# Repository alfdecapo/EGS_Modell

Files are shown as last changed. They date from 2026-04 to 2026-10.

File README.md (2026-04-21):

# EGS Modell
Dateispeicher und Entwicklungsdaten für das Einsatz-Gerüst-System als Modellbausatz.
Das Modell hat einen Maßstab 1:7,7.

Beispiel:
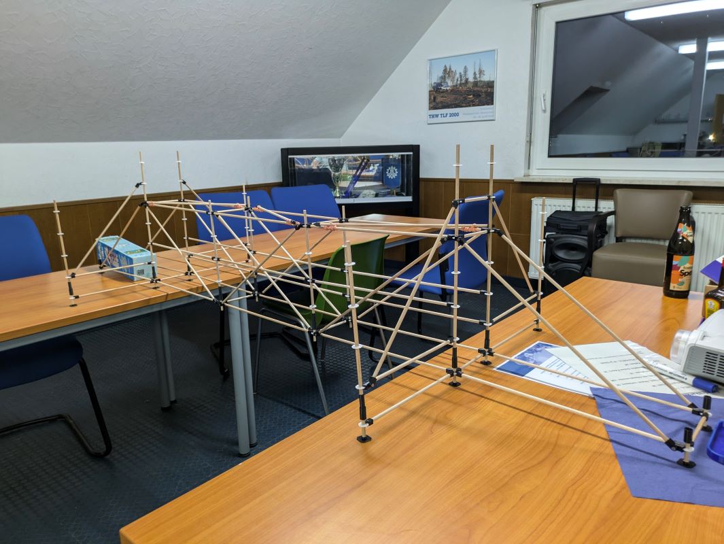
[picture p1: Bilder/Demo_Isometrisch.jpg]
Bild vom freitrageneden Steg


## 🛠️ Vorbereitung

Bevor du mit dem Druck startest, beachte bitte diesen Ablauf, um unnötige Druckstunden und Fehlkäufe bei den Zukaufteilen zu vermeiden.
### 1. Toleranz-Check (Schnappverbindungen)
Das Projekt setzt auf Schnappverbindungen. Da 3D-Drucker das Modell oft mit minimalen Abweichungen umsetzen, ist die Passgenauigkeit entscheidend:
* Testdruck: Drucke zuerst nur die Verbindungsstellen:
	* Flansch
	* Diagonale Keilschloss
	* Horizontale Keilschloss
* Anpassung: Sollten die Teile nicht sauber einrasten, [nimm die Korrekturen gezielt in der FreeCAD-Datei vor](#-software--mitwirken).

### 2. Umfang & Beschaffung
Da es sich um einen modularen Bausatz handelt, variiert der Bedarf je nach gewählter Gerüst-Größe.
 [Siehe dazu die Materialplanung.](Anleitungen/Materialplanung.md) 
 Es empfielt sich erst mit der Bodengruppe zu beginnen, da diese in fast jedem anderen Bausatz wiederfindet.

## 🏗️ Montageanleitungen
* [Materialplanung](Anleitungen/Materialplanung.md)
* [Zusammenbau Boden](Anleitungen/ZusammenbauBoden.md)
* [Zusammenbau Diagonale](Anleitungen/ZusammenbauDiagonale.md)
* [Zusammenbau Drehkupplung](Anleitungen/ZusammenbauDrehkupplung.md)
* [Zusammenbau Fuß](Anleitungen/ZusammenbauFuss.md)
* [Zusammenbau Riegel](Anleitungen/ZusammenbauRiegel.md)
* [Zusammenbau Vertikale](Anleitungen/ZusammenbauVertikale.md)

## ❓ Fragen & Problemlösungen
Sollten in den Montageanleitungen noch Fragen offen bleiben kann die FAQ Seite weiter helfen.

👉 **[Hier geht es zur separaten FAQ-Seite](FAQ.md)**

## 🛠 Software & Mitwirken

Das Projekt wird zukünftig primär mit **FreeCAD** entwickelt. Wenn du Änderungen vornehmen möchtest, nutze bitte die Dateien im Ordner `CAD Dateien/FreeCAD/`.

* **Download:** [FreeCAD herunterladen (Open Source)](https://www.freecad.org/)

### Workflow für Mitwirkende:
1. Quelldatei in **FreeCAD** bearbeiten.
2. Nach Änderungen die betroffenen Bauteile als **.stl** exportieren.
3. Die neuen **.stl** Dateien im Ordner **`Drucker Dateien/`** speichern.

## ⚙️ Export-Einstellungen
Damit die Druckdateien konsistent bleiben:
* **Format:** STL
* **Einheit:** mm
* **Speicherort:** `/Drucker Dateien/`

## 📄 Lizenz

Dieses Projekt ist unter der **GNU General Public License v3.0 (GPLv3)** lizenziert.

**Was das bedeutet:**
* ✅ **Freie Nutzung:** Du darfst die CAD-Dateien privat und kommerziell nutzen.
* ✅ **Änderungen:** Du darfst die Modelle verändern und verbessern.
* ⚠️ **Weitergabe:** Wenn du das Projekt oder eine veränderte Version davon verbreitest, **muss** dies ebenfalls unter der GPLv3 geschehen und der Quellcode (die originalen CAD-Dateien, nicht nur STLs!) muss offen zugänglich sein.

Details findest du in der [LICENSE](LICENSE) Datei.

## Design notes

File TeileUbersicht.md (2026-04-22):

# Übersicht über die Druck-Teile

|  | Dateiname | Bezeichnung der Anleitung | Anleitungen |
| - | - | - | - |
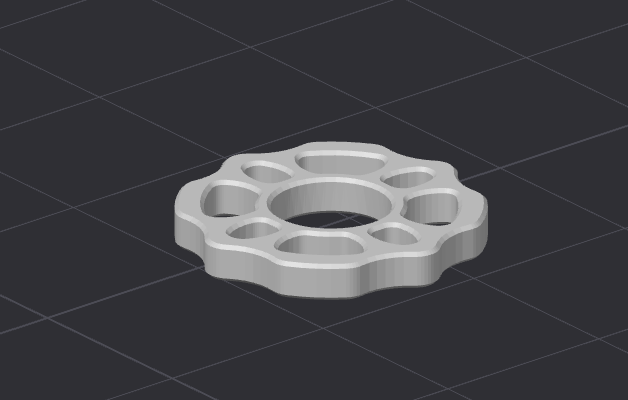
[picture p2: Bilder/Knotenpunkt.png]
Bild
|  | [Flansch 1zu7.7](Drucker-Dateien/Flansch-1zu7.7.STL) | Flansch | [Vertikalstangen](Anleitungen/ZusammenbauVertikale.md)<br>[Füße und Anfangstücke](Anleitungen/ZusammenbauFuss.md) |
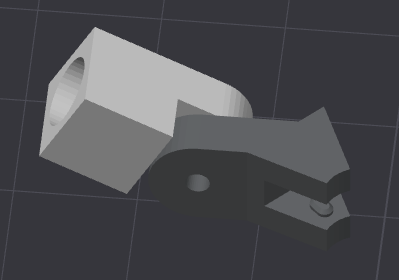
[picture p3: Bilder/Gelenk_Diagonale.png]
Bild
|  | [Diagonale Gelenk](Drucker-Dateien/Diagonale-Gelenk.STL) | Gelenk | [Diagonalstangen](Anleitungen/ZusammenbauDiagonale.md) |
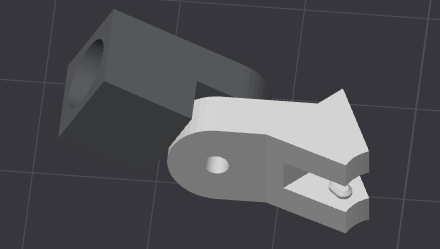
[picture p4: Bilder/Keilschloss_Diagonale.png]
Bild
|  | [Diagonale Keilschloss](Drucker-Dateien/Diagonale-Keilschloss.STL) | Keilschloss | [Diagonalstangen](Anleitungen/ZusammenbauDiagonale.md) |
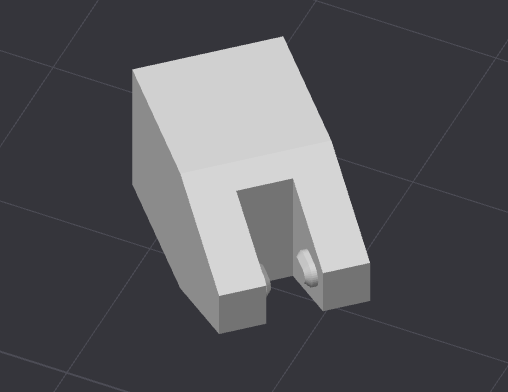
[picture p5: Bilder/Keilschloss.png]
Bild
|  | [Horizontale Keilschloss](Drucker-Dateien/Horizontale-Keilschloss.STL) | Keilschloss | [Riegel](Anleitungen/ZusammenbauRiegel.md) |
| [![Bild]()](Drucker-Dateien/Vertikalen-Verbinder.STL) | [Vertikalen Verbinder](Drucker-Dateien/Vertikalen-Verbinder.STL) | Adapter | [Vertikalstangen](Anleitungen/ZusammenbauVertikale.md) |
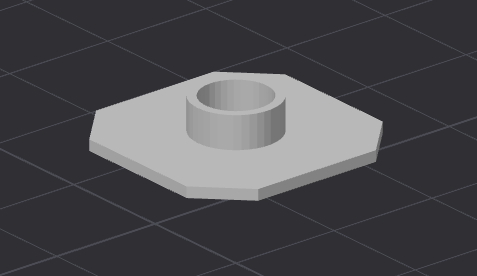
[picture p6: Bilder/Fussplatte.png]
Bild
|  | [Fuß](Drucker-Dateien/Fuß.STL) | Fuß | [Füße und Anfangstücke](Anleitungen/ZusammenbauFuss.md) |
| [![Bild]()](Drucker-Dateien/Fußadapter-Simpel.STL) | [Fußadapter Simpel](Drucker-Dateien/Fußadapter-Simpel.STL) | Adapter | [Füße und Anfangstücke](Anleitungen/ZusammenbauFuss.md) |
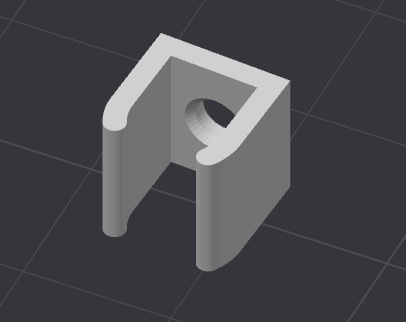
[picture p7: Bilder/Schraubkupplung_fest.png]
Bild
|  | [Drehkupplung Klemme](Drucker-Dateien/Drehkupplung-Klemme.STL) | Klemme | [Drehkupplung](Anleitungen/ZusammenbauDrehkupplung.md) |
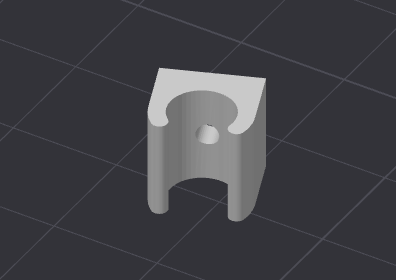
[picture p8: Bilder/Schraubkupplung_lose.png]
Bild
|  | [Drehkupplung Lose](Drucker-Dateien/Drehkupplung-Lose.STL) | Lose | [Drehkupplung](Anleitungen/ZusammenbauDrehkupplung.md) |
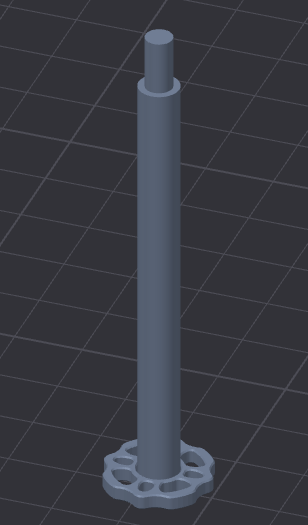
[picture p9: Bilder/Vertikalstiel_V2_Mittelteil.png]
Bild
| | [Vertikalstiel V2 Mittelteil](Drucker-Dateien/Vertikalstiel_V2_Mittelteil.STL)|Stiel_V2_Mittelteil|[Stiel_V2_Mittelteil](Anleitungen/Zusammenbau_Vertikalstiel_V2.md)|

## Sonstige Dateien

|  | Dateiname | Kommentar |
| - | - | - |
| [![Bild]()] | [Boden 3m breit](Drucker-Dateien/Boden-3m-breit.STL) | Der breite 3m Boden in einem Stück. Passt nicht in die meisten Drucker hinein |
| [![Bild]()] | [Boden 3m schmal](Drucker-Dateien/Boden-3m-schmal.STL) | Der schmale 3m Boden in einem Stück. Passt nicht in die meisten Drucker hinein |
| [![Bild]()] | [Flansch](Drucker-Dateien/Flansch.STL) | Der Flansch in orginal Größe |

---
[Zurück zur Hauptanleitung](README.md)

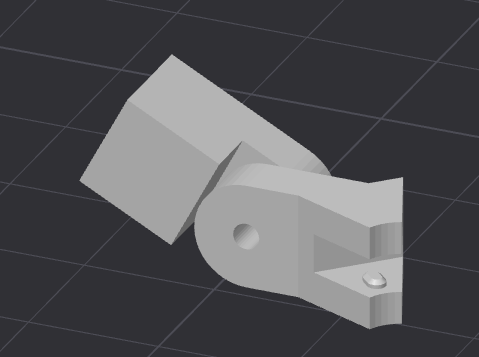
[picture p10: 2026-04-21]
Bilder/Klemmschloss_Diagonale.png

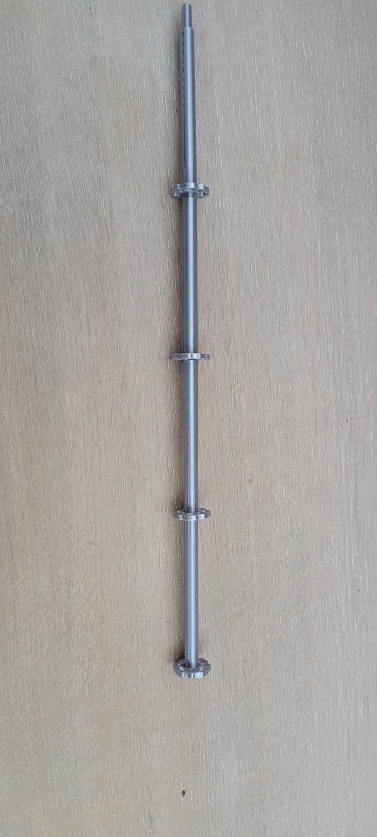
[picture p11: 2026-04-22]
Bilder/Vertikalstiel_V2_Prototyp.jpg

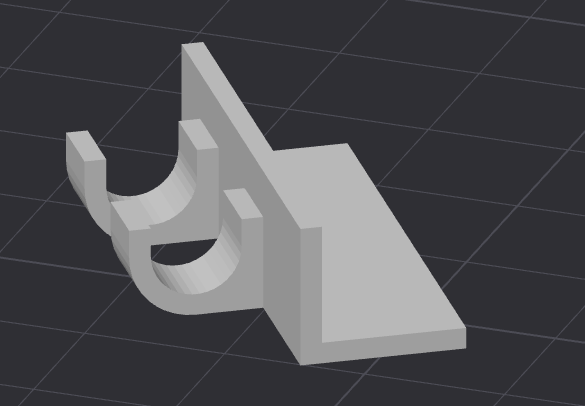
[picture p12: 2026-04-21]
Bilder/Bodenadapter schmal.png

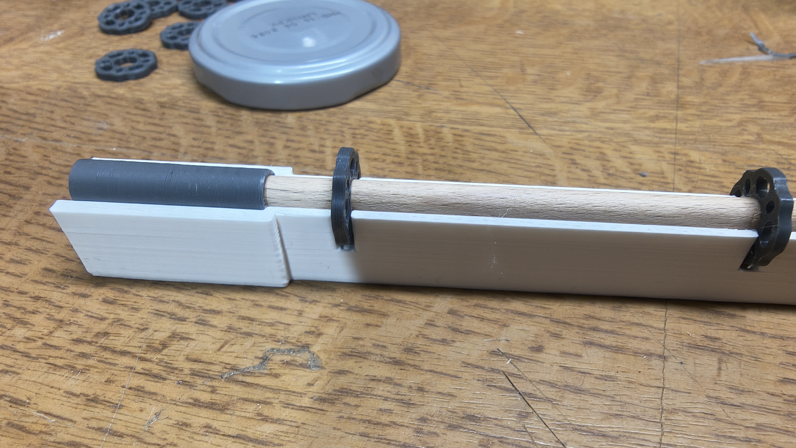
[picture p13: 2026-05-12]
Bilder/Vertikalschablone/Vertikalschablone_Kopf.jpg

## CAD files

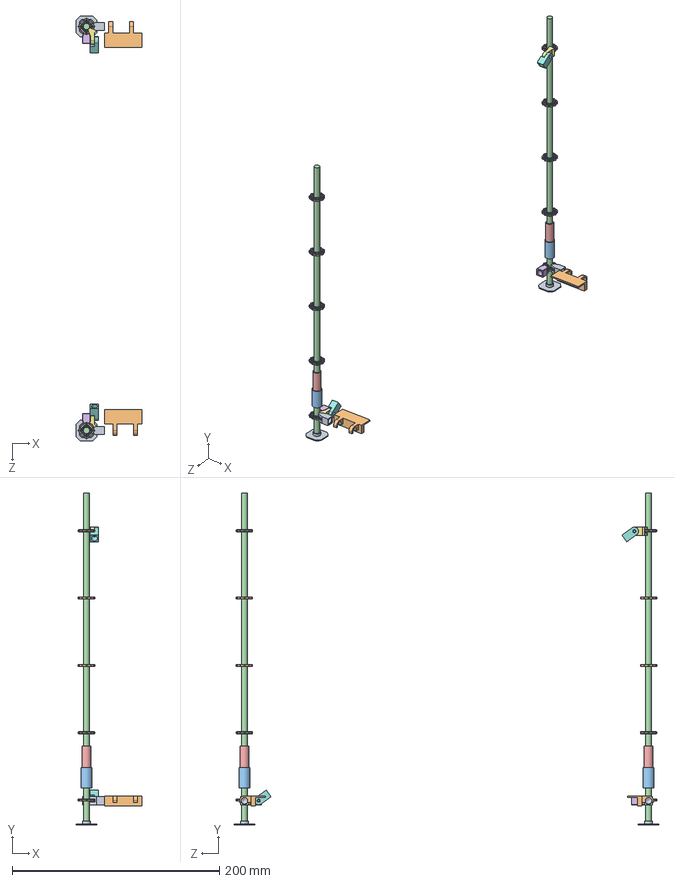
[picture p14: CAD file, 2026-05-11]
CAD Dateien/Teildruck 7.7/Ursprungsdateien Solid Works/Gesammtbau.SLDASM
63.5 x 320.4 x 410.0 mm
Fuß x 2
Rosette 1zu7.7 x 10
Fußadapter Simpel v2 x 2
Holzstangen x 4
Vertikalen Verbinder x 2
Rosettenadapter-Gerade v4 x 2
Rosettenadapter-Diagonale Verbinder v2 x 2
Rosettenadapter-Diagonale Stange x 2
Rosettenadapter-Gerade v5 x 2
Bodenadapter breit v2 x 2

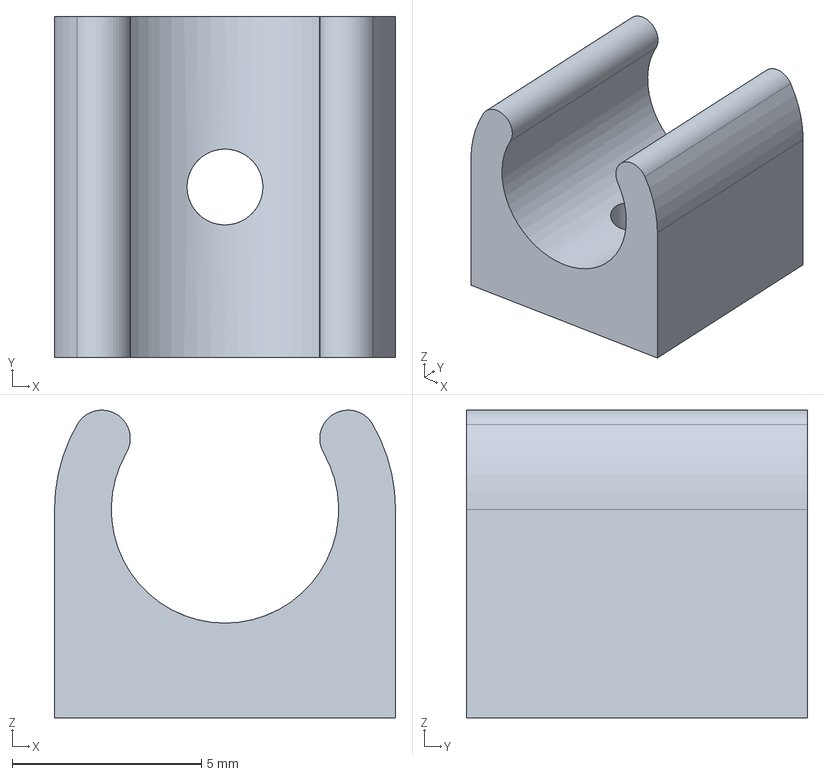
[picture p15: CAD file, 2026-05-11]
CAD Dateien/Teildruck 7.7/Drehkupplung Klemme.FCStd
9.00 x 9.00 x 8.12 mm

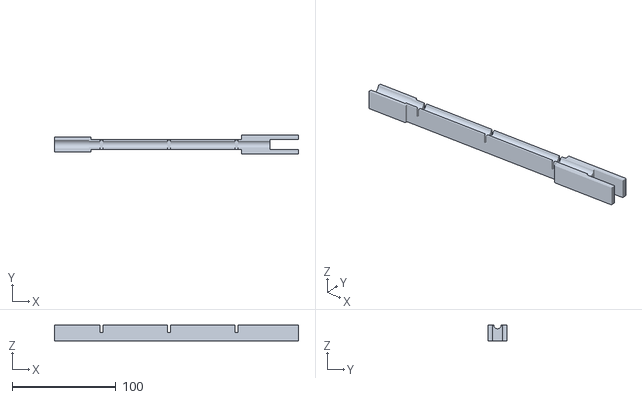
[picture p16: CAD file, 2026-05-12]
Drucker Dateien/Teildruck 7.7/Schablone EGS Vertikalstiel - Anfangsteil.stl
235.0 x 18.0 x 15.0

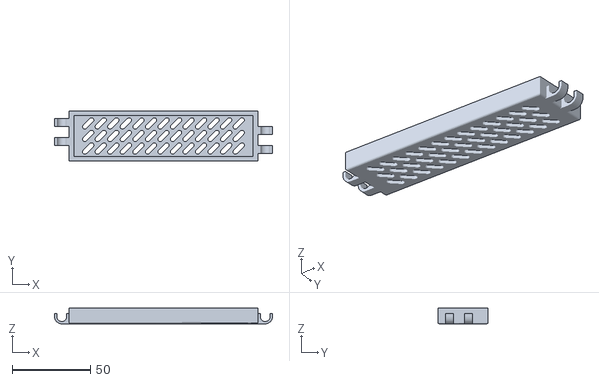
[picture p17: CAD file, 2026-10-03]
Drucker Dateien/Volldruck 7.7/Boden - 1m - Schmal.stl
138.9 x 32.0 x 10.0

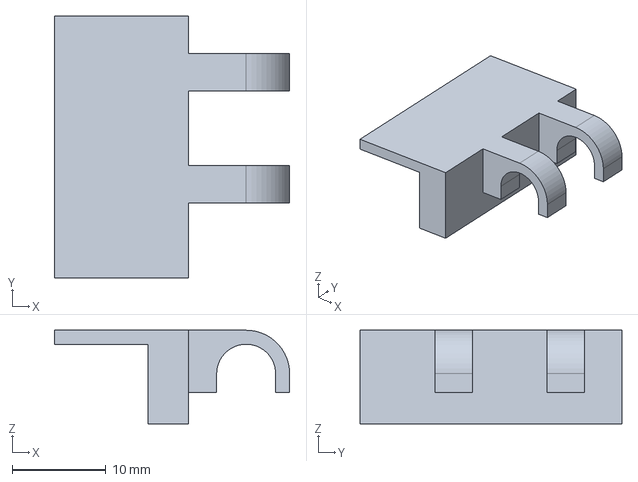
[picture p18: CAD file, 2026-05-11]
CAD Dateien/Teildruck 7.7/Bodenadapter schmal.FCStd
25.1 x 28.0 x 10.0 mm

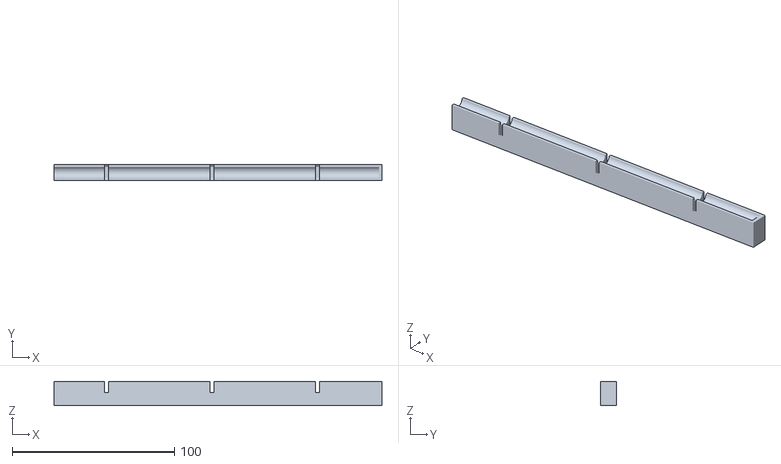
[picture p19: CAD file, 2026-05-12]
Drucker Dateien/Teildruck 7.7/Schablone EGS Vertikalstiel - Endteil.stl
202.2 x 10.0 x 15.0

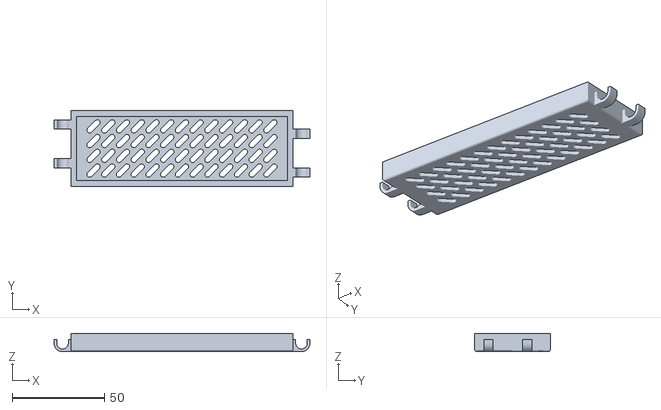
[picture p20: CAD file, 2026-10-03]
Drucker Dateien/Volldruck 7.7/Boden - 1m - Breit.stl
139.0 x 41.0 x 10.0

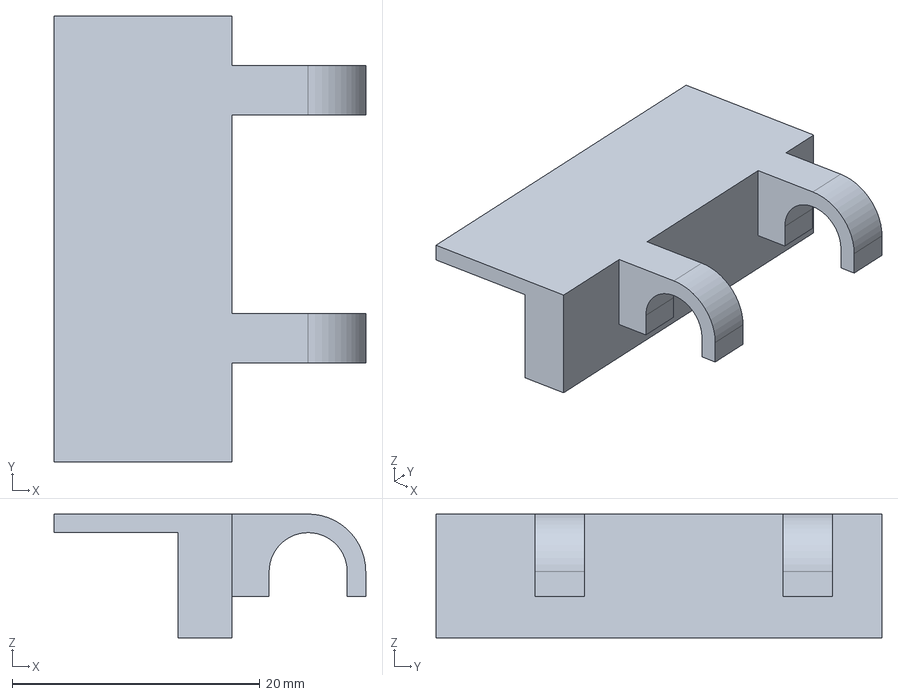
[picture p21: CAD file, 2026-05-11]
CAD Dateien/Teildruck 7.7/Bodenadapter breit.FCStd
25.1 x 36.0 x 10.0 mm

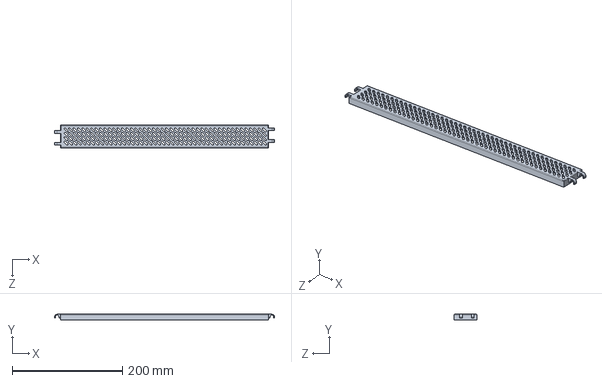
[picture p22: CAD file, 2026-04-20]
CAD Dateien/Teildruck 7.7/Ursprungsdateien Solid Works/Boden 3m breit.SLDPRT
399.3 x 10.0 x 41.0 mm

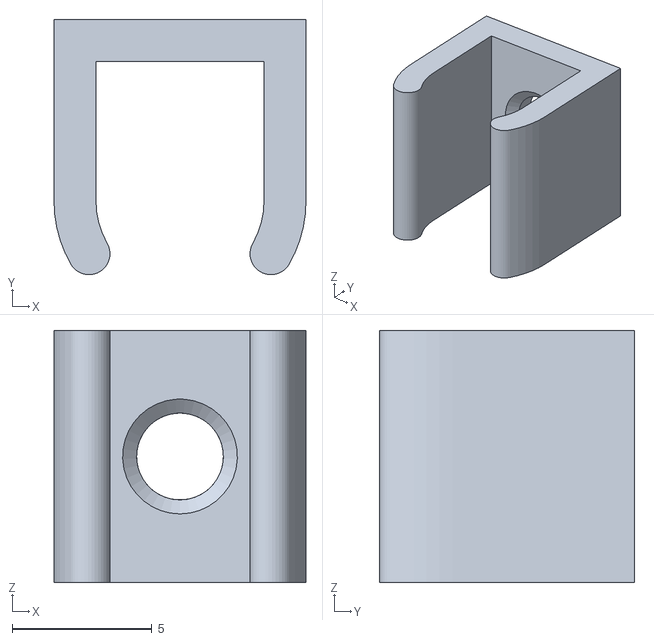
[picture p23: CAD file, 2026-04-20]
Drucker Dateien/Teildruck 7.7/Drehkupplung Lose.STL
9.00 x 9.12 x 9.00

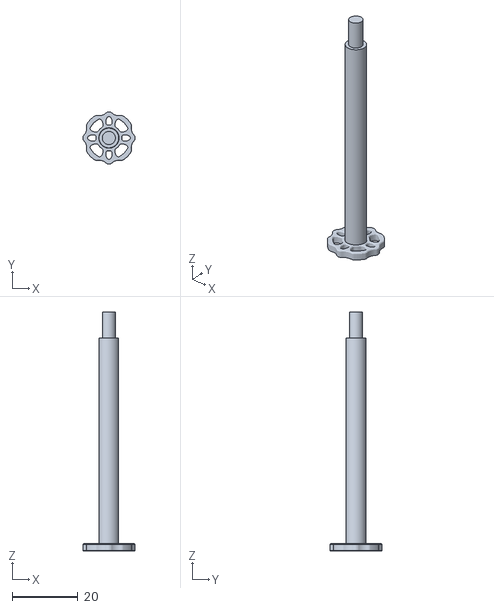
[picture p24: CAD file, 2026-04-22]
Drucker Dateien/Volldruck 7.7/Vertikalstiel_V2_Mittelteil.stl
16.0 x 16.0 x 72.9

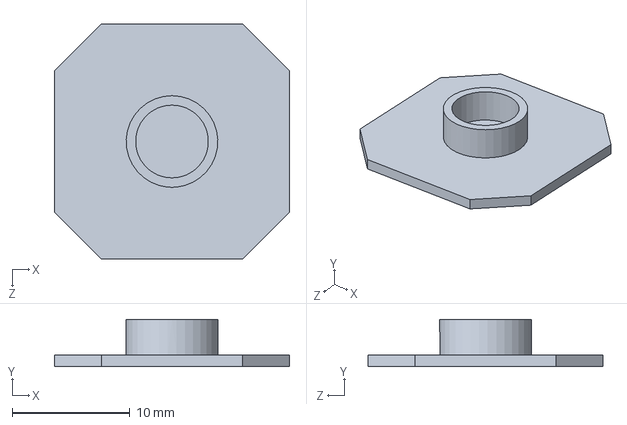
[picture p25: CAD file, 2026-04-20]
CAD Dateien/Teildruck 7.7/Ursprungsdateien Solid Works/Fuß.SLDPRT
20.0 x 4.00 x 20.0 mm

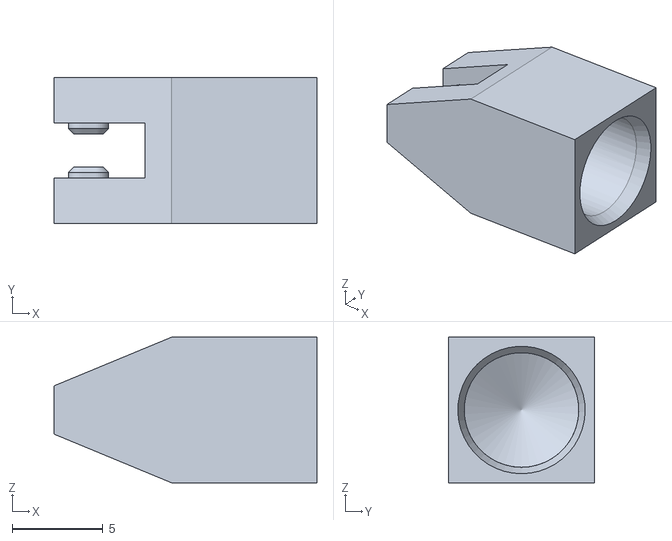
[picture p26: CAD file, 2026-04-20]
Drucker Dateien/Teildruck 7.7/Horizontale Keilschloss.STL
14.5 x 8.00 x 8.00

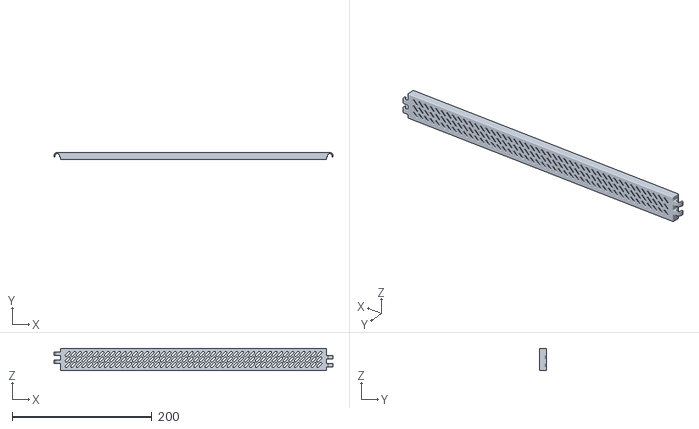
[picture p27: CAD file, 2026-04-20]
Drucker Dateien/Volldruck 7.7/Boden 3m schmal.STL
399.3 x 10.0 x 32.0

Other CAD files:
CAD Dateien/Teildruck 7.7/Ursprungsdateien Solid Works/Drehkupplung Klemme.SLDPRT
CAD Dateien/Teildruck 7.7/Drehkupplung Lose.FCStd
CAD Dateien/Teildruck 7.7/Diagonale Keilschloss.FCStd
CAD Dateien/Teildruck 7.7/Ursprungsdateien Solid Works/Diagonale Gelenk.SLDPRT
CAD Dateien/Teildruck 7.7/Diagonale Gelenk.FCStd
CAD Dateien/Teildruck 7.7/Flansch.FCStd
CAD Dateien/Teildruck 7.7/Fuß.FCStd
CAD Dateien/Teildruck 7.7/Fußadapter.FCStd
CAD Dateien/Teildruck 7.7/Horizontale Keilschloss.FCStd
CAD Dateien/Teildruck 7.7/Ursprungsdateien Solid Works/Boden 3m schmal.SLDPRT
CAD Dateien/Teildruck 7.7/Ursprungsdateien Solid Works/Bodenadapter breit.SLDPRT
CAD Dateien/Teildruck 7.7/Ursprungsdateien Solid Works/Bodenadapter schmal.SLDPRT
CAD Dateien/Teildruck 7.7/Ursprungsdateien Solid Works/Diagonale Keilschloss.SLDPRT
CAD Dateien/Teildruck 7.7/Ursprungsdateien Solid Works/Drehkupplung Lose.SLDPRT
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

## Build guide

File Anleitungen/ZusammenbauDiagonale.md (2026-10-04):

# Zuammbauanleitung Diagonale
Das nutzen eines Nagels ist getestet und funktioniert, ist aber schwierig zu bauen. 
Sobald die Schraube getestet ist wir die Anleitung umgeschrieben

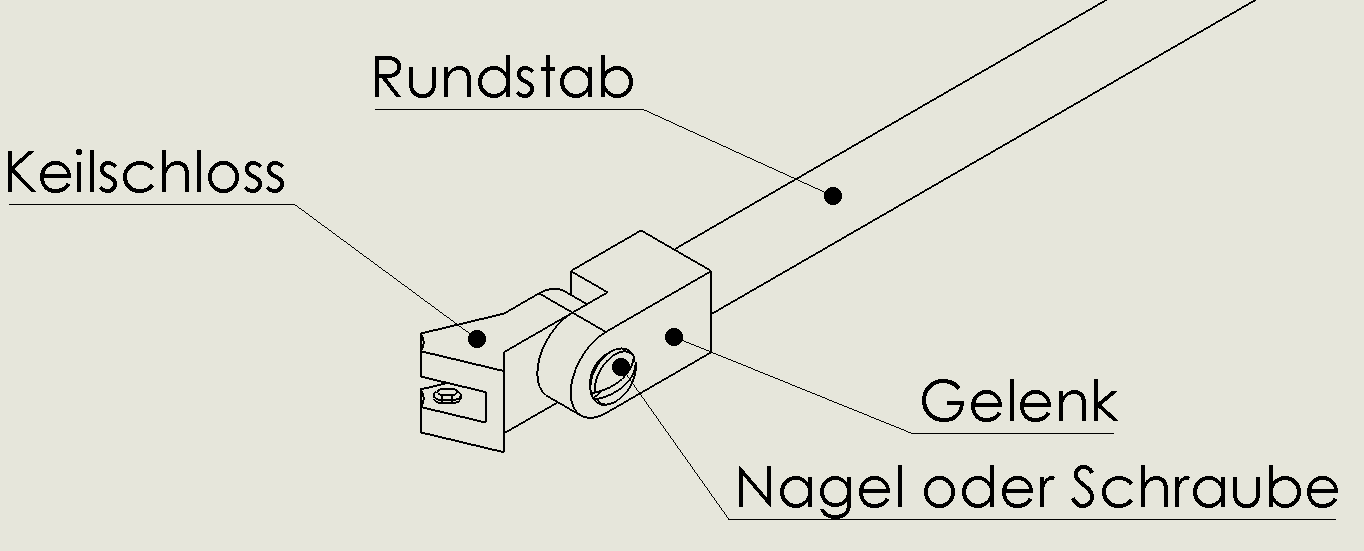
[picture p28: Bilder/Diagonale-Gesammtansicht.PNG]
Bild mit dem Zusammenbau einer Seite der Diagonalen und Beschriftung der Teile


## Variationen
Für die Stückliste der einzelnen Variationen siehe [hier](Materialplanung.md#diagonalen).
Zur Vereinfachung werden hier nur Rundstab, Nagel, Gelenk und Keilschloss verwendet.

👉 **[Hier geht es zur separaten Druckteile-Seite](../TeileUbersicht.md)**

## 🛠 Zusammenbau

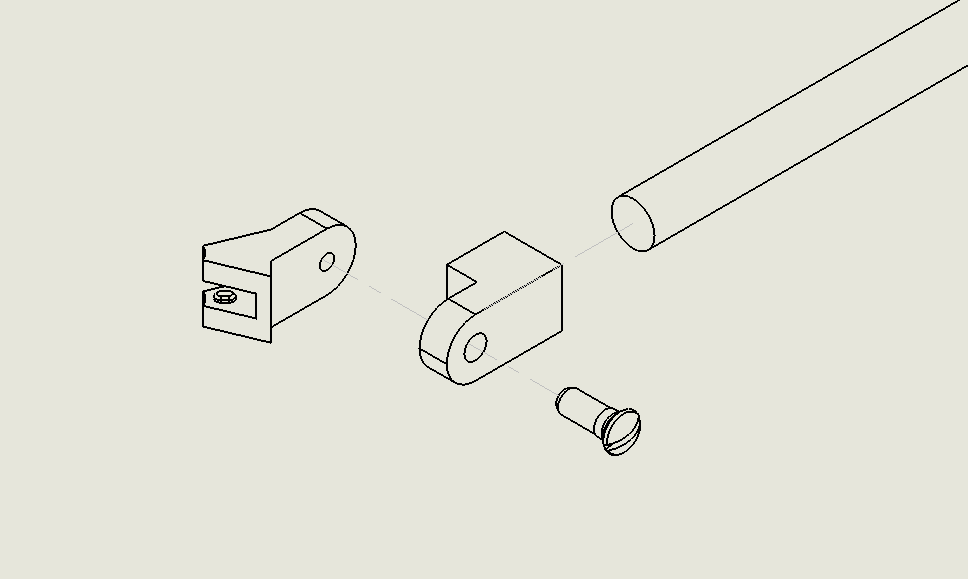
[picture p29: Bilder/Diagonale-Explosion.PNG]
Explosionsdarstellung einer Seite einer Daigonalen um den Ablauf des Zusammenbaues sehen zu können


* Länge den Rundstab auf die benötiget Länge ab
	* 2x1 -> 269mm
	* 2x2 -> 338mm
	* 2x3 -> 435mm
* Klebe auf jede Seite ein Gelenk so, dass das Ende des Rundstabes in das große Loch des Gelenkes steckt.
Achte dabei darauf, dass die Gelenke auf beiden Seiten gleich ausgerichtet sind. Der Kleber ist nicht sofort fest,du kannst den Tisch als hilfe nehmen.
* Schraube nun die Schraube in das Keilschloss, so dass die Schraube durch das Gelenk in das Keilschloss 
geht und das Keilschloss von der Schraube weg zeigt. Solltest du den Nagel verwenden befolge stantdessen die Unterschritte:
	* Kürze den Nagel auf ca 7mm.
	* Presse mit hilfe eines Schraubstockes den Nagel durch Gelenk und das Keilschloss. Der Nagel sollte nur im Keilschloss halten
* Überprüfe ob sich die Gelenke bewegen lassen

## 📄 Relevante Dateien
* [Diagonale Gelenk](../Drucker%20Dateien/Teildruck%207.7/Diagonale%20Gelenk.STL)
* [Diagonale Keilschloss](../Drucker%20Dateien/Teildruck%207.7/Diagonale%20Keilschloss.STL)
---
[Zurück zur Hauptanleitung](../README.md)

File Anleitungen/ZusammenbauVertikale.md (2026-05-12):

# Zuammbauanleitung Vertikalstangen

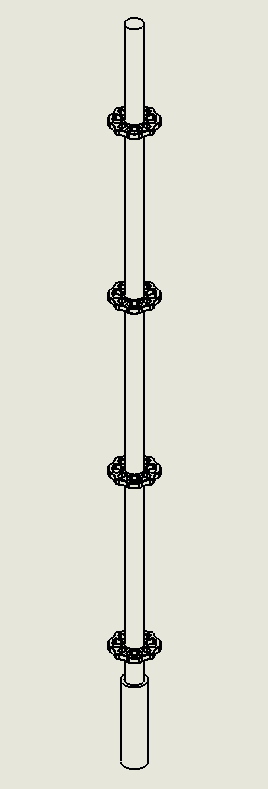
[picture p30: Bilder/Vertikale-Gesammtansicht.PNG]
Bild mit dem Zusammenbau einer Seite der Diagonalen und Beschriftung der Teile


## Variationen
Für die Stückliste der einzelnen Variationen siehe [hier](Materialplanung.md#sonstige).
Zur Vereinfachung werden hier nur Rundstab, Flansch und Adapter verwendet.

👉 **[Hier geht es zur separaten Druckteile-Seite](../TeileUbersicht.md)**

## 🛠 Zusammenbau
* Länge den Rundstab auf die benötiget Länge ab
	* 1,0 m -> 129 mm
	* 1,5 m -> 194 mm
	* 2,0 m -> 259 mm
	* 2,5 m -> 324 mm
	* 3,0 m -> 389 mm
* Markiere die Seite die unten sein soll.
* Markiere nun von unten wo die Flansche sein sollen:
	*  26 mm
	*  91 mm
	* 156 mm
	* 221 mm
	* 286 mm
	* 351 mm
* Schiebe die Flansche auf den Rundstab in die Nähe ihrer Markierung
* Klebe die Flansche oberhalb Markierung fest
Achte dabei darauf, dass alle Flansche in die selbe Richtung zeigen.
Der Kleber ist nicht sofort fest,du kannst den Tisch als hilfe nehmen.
* Klebe die Unterseite des Rundstabes in das kleine Loch des Adapters

## Alternativer Zusammenbau mit der Schablone
* Drucke die Schablone für die Vertikalstiele aus (sie passt diagonal auf die meisten Druckplatten): [Schablone zum Ausrichten der Flansche - Anfangsteil](../Drucker%20Dateien/Teildruck%207.7/Schablone%20EGS%20Vertikalstiel%20-%20Anfangsteil.stl) und [Schablone zum Ausrichten der Flansche - Endteil](../Drucker%20Dateien/Teildruck%207.7/Schablone%20EGS%20Vertikalstiel%20-%20Endteil.stl) und klebe beide Teile bündig zusammen:
  
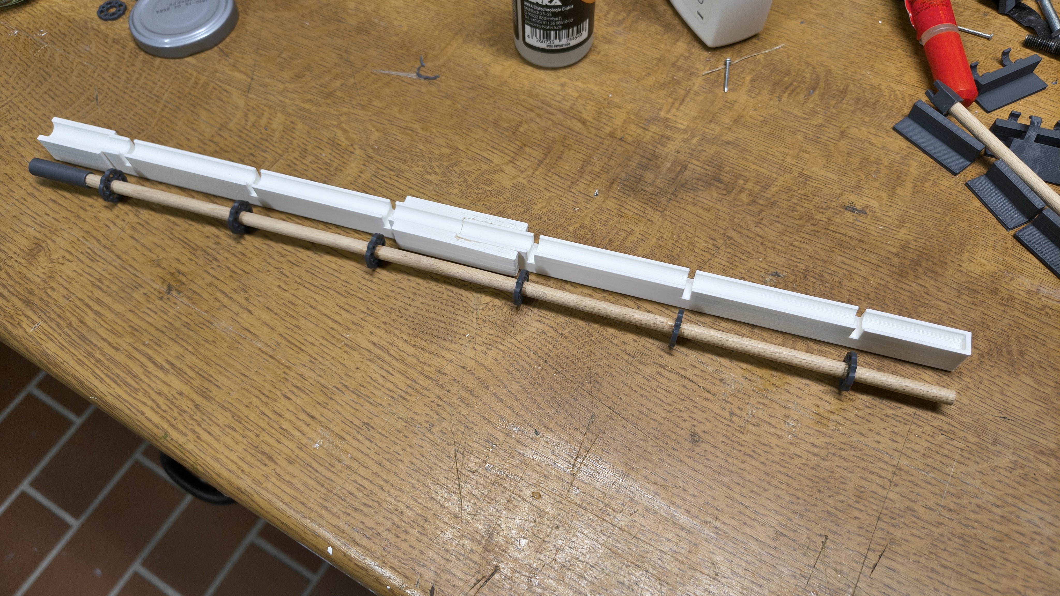
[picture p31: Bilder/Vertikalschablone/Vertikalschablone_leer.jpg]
Bild mit Vertikalstiel-Schablone zum Ausrichten der Flansche

* wer mag, kann die Überblattung der beiden Schablonenteile auch noch mit zwei zusätzlichen Schrauben sichern (Löcher vorher selbst bohren):

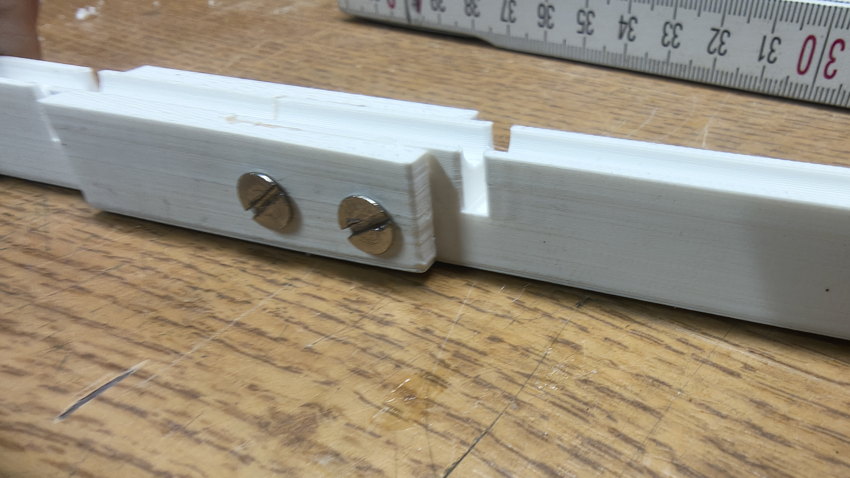
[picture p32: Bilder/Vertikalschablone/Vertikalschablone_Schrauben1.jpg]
Bild mit Vertikalstiel-Schablone und zusätzlichen Schrauben
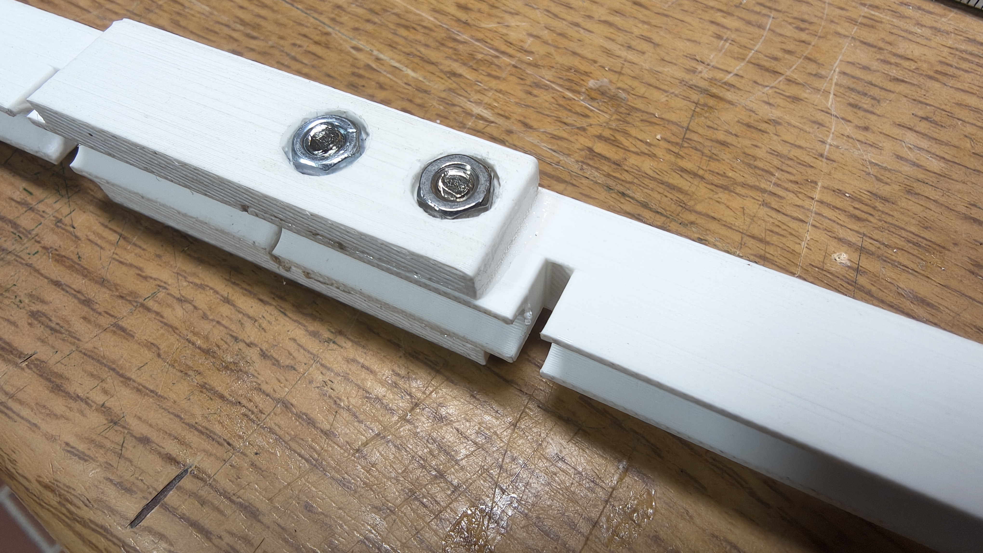
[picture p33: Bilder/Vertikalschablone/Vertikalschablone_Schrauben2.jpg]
Bild mit Vertikalstiel-Schablone und zusätzlichen Schrauben
   

* Klebe den vertikalen Verbinder (die 30mm lange schmale Hülse)  fest und kontrolliere danach die Gesamtlänge der Vertikalstiele
	* Gesamtlänge Vertikalstiele incl. Vertikalverbinder
 		* 1,0 m -> 144 mm
		* 1,5 m -> 209 mm
		* 2,0 m -> 274 mm
		* 2,5 m -> 339 mm
		* 3,0 m -> 404 mm
* klebe die Flansche an die ungefähren Stellen auf dem Vertikalstiel, die Schablone hilft dann beim korrekten Ausrichten auf 0.5mm genau. Achte auch hier darauf, dass alle Flansche in die selbe Richtung gedreht sind.
  
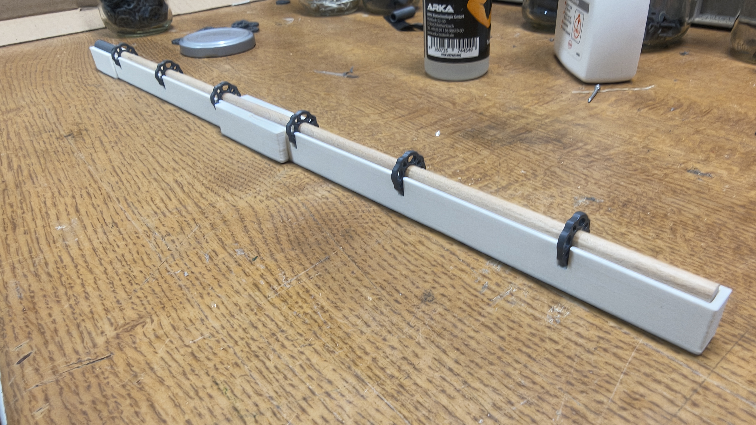
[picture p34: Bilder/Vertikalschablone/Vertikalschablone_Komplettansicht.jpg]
Bild mit Vertikalstiel 3m in dr Schablone zum Ausrichten der Flansche


## 📄 Relevante Dateien
* [Flansch(1:7)](../Drucker%20Dateien/Teildruck%207.7/Flansch%201zu7.7.STL)
* [Vertikalen Verbinder](../Drucker%20Dateien/Teildruck%207.7/Vertikalen%20Verbinder.STL)
* [Schablone zum Ausrichten der Flansche - Anfangsteil](../Drucker%20Dateien/Teildruck%207.7/Schablone%20EGS%20Vertikalstiel%20-%20Anfangsteil.stl)
* [Schablone zum Ausrichten der Flansche - Endteil](../Drucker%20Dateien/Teildruck%207.7/Schablone%20EGS%20Vertikalstiel%20-%20Endteil.stl)
---
[Zurück zur Hauptanleitung](../README.md)

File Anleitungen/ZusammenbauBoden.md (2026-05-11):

# Zuammbauanleitung Einlegeböden
> [!NOTE]
> Die Anleitung bezieht sich auf die zusammengesätzten Böden. 
> Solltest du es geschafft haben die ausmodilierten Böden in deinen Druckraum zu patzieren 
> kannst du diese Anleitung überspringen.

## Variationen
Für die Stückliste der einzelnen Variationen siehe [hier](Materialplanung.md#boden).
Zur Vereinfachung werden hier nur Adapter und Holzplatte verwendet.

👉 **[Hier geht es zur separaten Druckteile-Seite](../TeileUbersicht.md)**

## 🛠 Zusammenbau
* Schneide die Holzplatte auf die gewünschten Maße zu.
	* Breit 3m -> 36 x 369 mm
	* Breit 1m -> 36 x 109 mm
	* Schmal 3m -> 28 x 369 mm
	* Schmal 1m ->  28 x 109 mm
* Klebe auf jeder der kurzen Seiten der Holzplatte einen Adapter, so dass die Haken von der Holzplatte entfernt sind

## 📄 Relevante Dateien
* [Bodenadpter breit](../Drucker%20Dateien/Teildruck%207.7/Bodenadapter%20breit.STL)
* [Bodenadpter breit](../Drucker%20Dateien/Teildruck%207.7/Bodenadapter%20schmal.STL)
---
[Zurück zur Hauptanleitung](../README.md)

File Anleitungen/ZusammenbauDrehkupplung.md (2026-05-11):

# Zuammbauanleitung Drehkupplung
Es ewerden zwei M6 Schrauben benötigt um die Kraft an die richtigen Stellen zu bringen.

## Variationen
Für die Stückliste der einzelnen Variationen siehe [hier](Materialplanung.md#sonstige).
Zur Vereinfachung werden hier nur Nagel, Lose und Klemme verwendet.

👉 **[Hier geht es zur separaten Druckteile-Seite](../TeileUbersicht.md)**

## 🛠 Zusammenbau
* Verbingung durch Nagel
	* Kürze den Nagel auf ca 3mm.
	* Presse mit hilfe eines Schraubstockes den Nagel durch Lose in die Klemme.
Platziere auf beiden Seiten des Nagels eine M6 Schraube um das Druckteil nicht zu beschädigen.
* Überprüfe ob sich die Gelenke bewegen lassen

## 📄 Relevante Dateien
* [Drehkupplung Lose](../Drucker%20Dateien/Teildruck%207.7/Drehkupplung%20Gelenk.STL)
* [Drehkupplung Klemme](../Drucker%20Dateien/Teildruck%207.7/Drehkupplung%20Klemme.STL)
---
[Zurück zur Hauptanleitung](../README.md)

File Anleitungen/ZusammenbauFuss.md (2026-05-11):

# Zuammbauanleitung Standfuß und Anfangsstück
Die Teile sind so klein, dass sie in ein Objekt vereint wurden.
Für das Anfangstück wird der letzte Schritt übersprungen.
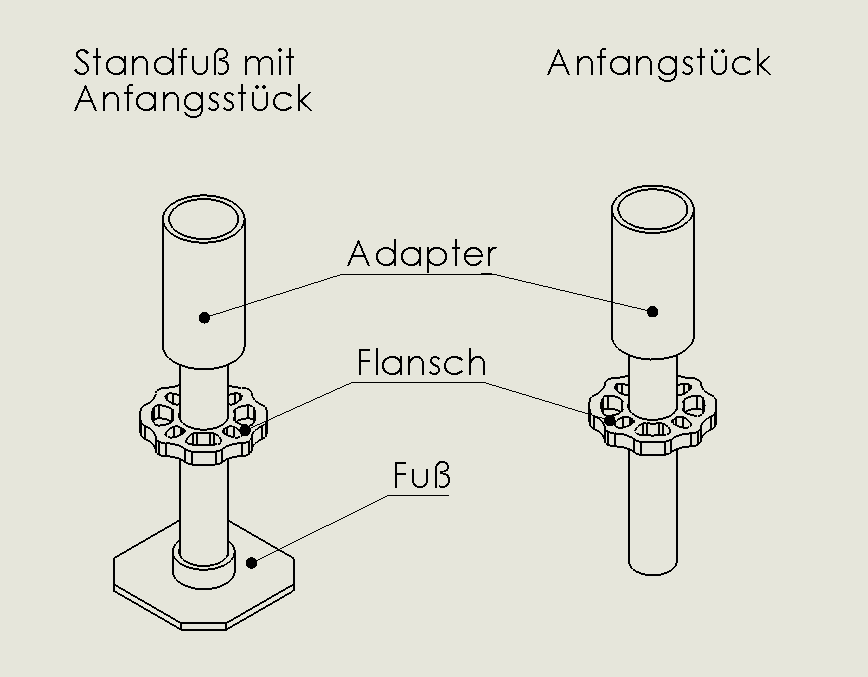
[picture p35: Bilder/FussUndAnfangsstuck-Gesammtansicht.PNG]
Bild mit dem Zusammenbau von Fuß und Anfangstück mit Beschriftung der Teile


## Variationen
Für die Stückliste der einzelnen Variationen siehe [hier](Materialplanung.md#sonstige).
Zur Vereinfachung werden hier nur Rundstab, Flansch, Adapter und Fuß verwendet.

👉 **[Hier geht es zur separaten Druckteile-Seite](../TeileUbersicht.md)**

## 🛠 Zusammenbau
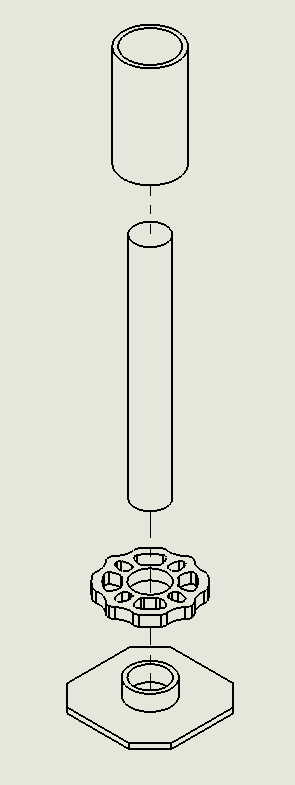
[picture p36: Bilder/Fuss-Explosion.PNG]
Explosionsdarstellung des Fußes um den Ablauf des Zusammenbaues sehen zu können


* Länge den Rundstab auf 44mm Länge ab.
* Markiere die Seite die unten sein soll.
* Markiere nun von unten 22mm weiter oben wo der Flansch sein soll.
* Schiebe einen Flansch auf den Rundstab und blebe ihn oberhalb der Markierung fest.
* Klebe den Rundstab (unmarkierte Seite) in das kleine Loch des Adapters.
* Für das Anfangsstück überspringe diesen Schritt.
Klebe die Unterseite des Rundstabes in die runde Vertiefung des Fußes.
Achte dabei darauf, dass die kleinen Löcher des Flansches zu den seiten des Fußes zeigen.

## Weiter Tipps zum Zusammenbau
* Nach dem Ankleben des Knotenstücks an das Anfangsstück das Anfangsstück jeweils oben und unten in eine Fußplatte stecken und waagerecht trocknen lassen
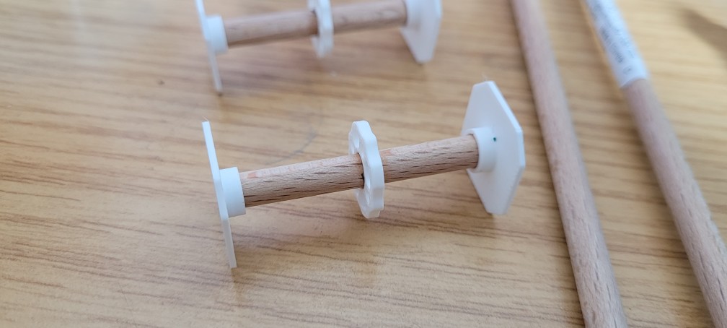
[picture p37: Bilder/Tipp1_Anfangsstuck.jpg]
Bild zum Tipp


## 📄 Relevante Dateien
* [Flansch](../Drucker%20Dateien/Teildruck%207.7/Flansch.STL)
* [Fuß](../Drucker%20Dateien/Teildruck%207.7/Fuß.STL)
* [Fußadapter Simpel](../Drucker%20Dateien/Teildruck%207.7/Fußadapter%20Simpel.STL)
---
[Zurück zur Hauptanleitung](../README.md)

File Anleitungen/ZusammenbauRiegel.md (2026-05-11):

# Zuammbauanleitung Riegel 
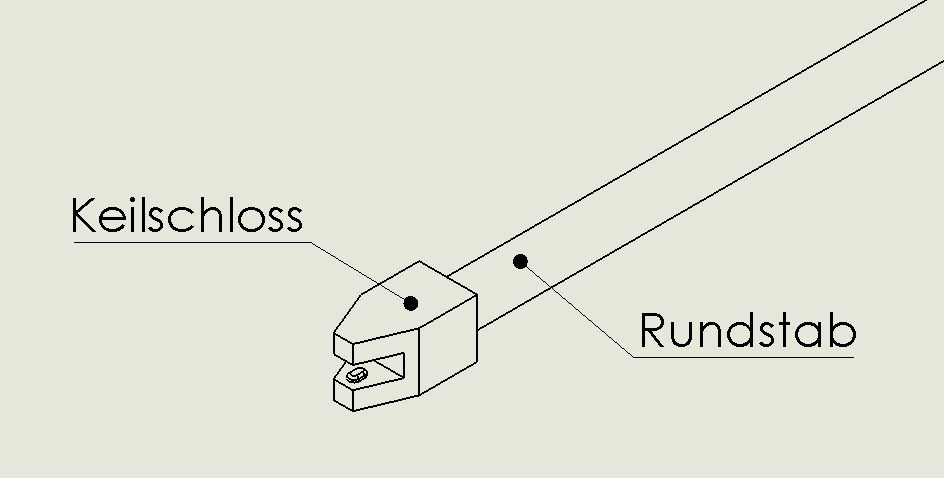
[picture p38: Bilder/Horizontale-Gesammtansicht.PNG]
Bild mit dem Zusammenbau einer Seite der Riegel und Beschriftung der Teile


## Variationen
Für die Stückliste der einzelnen Variationen siehe [hier](Materialplanung.md#riegel).
Zur Vereinfachung werden hier nur Rundstab und Keilschloss verwendet.

👉 **[Hier geht es zur separaten Druckteile-Seite](../TeileUbersicht.md)**

## 🛠 Zusammenbau

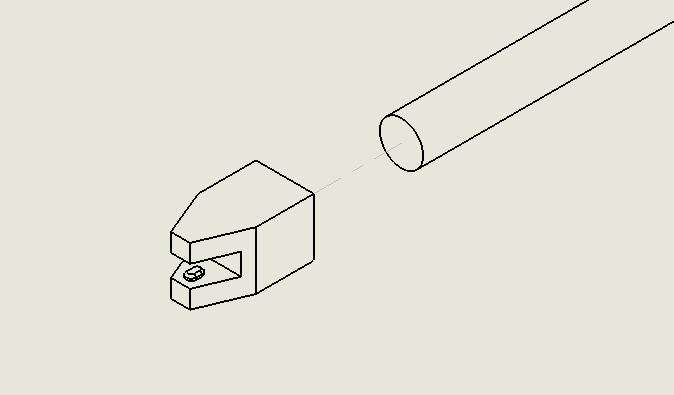
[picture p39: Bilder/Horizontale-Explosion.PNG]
Explosionsdarstellung einer Seite einer Riegel um den Ablauf des Zusammenbaues sehen zu können


* Länge den Rundstab auf die benötiget Länge ab
	* 2x1 -> 110mm
	* 2x2 -> 240mm
	* 2x3 -> 370mm
* Klebe auf jede Seite ein Keilschloss so, dass das Ende des Rundstabes in das runde Loch des Keilschloss steckt.
Achte dabei darauf, dass die Keilschlösser auf beiden Seiten gleich ausgerichtet sind. Der Kleber ist nicht sofort fest,du kannst den Tisch als hilfe nehmen.

## 📄 Relevante Dateien
* [Horizontale Keilschloss](../Drucker%20Dateien/Teildruck%207.7/Horizontale%20Keilschloss.STL)
---
[Zurück zur Hauptanleitung](../README.md)

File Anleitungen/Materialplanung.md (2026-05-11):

# 📋 Materialplanung & Stücklisten

EGS-Bausätze sind oft größer als man glaubt. Je nachdem welchen Bausatz du umsetzten möchtest 
werden viele Stangen, und somit viele Zukaufteile, benötigt. Die Teile für den Steg - freitragend 9m 
haben in meinem Fall ca. 120€ gekostet. Mache dir daher vorher Gedanken wieviel du Ausgeben möchtest
und welchen Verwendungszweck du hast (Übungsmodell - viele Ersatzteile vs. Ausstellungsstück).

## Inhaltsverzeichnis
* [Nicht gedruckte Teile](#nicht-gedruckte-teile)
* [Bausätze](#bausatze)
* [Gerüste]
* [Einzelteile](#einzeilteile)
	* [Vertikalstiele](#vertikalstiele)
	* [Riegel (Horizontalen)](#riegel-horizontalen)
	* [Diagonalen](#diagonalen)
	* [Böden](#boden)
	* [Sonstige](#sonstige)

## Nicht gedruckte Teile
Selbst in dem kleinen Maßstab passen die meisten Stangen nicht in das Druckvolumen üblicher 3D-Drucker.
Zudem sind in der größe Holz oder Messing stabiler als gedruckte Teile. Nachfolgend die Teile die nicht 
aus dem 3D-Drucker kommen:
* Bucherundstab 6mm (Alternativ Messingrohr)
* Holzplatte 8mm dick
* Nagel D2x45 (Alternativ: Schraube M2x8mm mit Linsenkopf)
* Bastelkleber

## Bausätze
Boah! Voll leer hier! Ich hatte noch keine Zeit die Teilelisten aus den EGS-Handbücher zu importieren.
Jeder OV sollte diese aber haben. Nutze bitte diese in der Zwischenzeit.
<<<<<<< HEAD
| Bezeichnung | BS 1 | BS 2 | BS 3 | BS4 | BS 5 | ∑ BS 1-5 | Knotenpunkte |
|---|---|---|---|-----|---|---|---|
| Vertikalstiel 100 |2 | |2 |4 | |8 | 16 |
| Vertikalstiel 150 |2 | | | |2 |4 | 12 |
| Vertikalstiel 200 |3 |4 | |1 |2 |10 | 40 |
| Vertikalstiel 300 | | |3 |2 |3 |8 | 48 |
| | | | | | | | 116 |

| Bezeichnung | BS 1 | BS 2 | BS 3 | BS4 | BS 5 | ∑ BS 1-5 | Keilschlösser |
|---|---|---|---|-----|---|---|---|
| Riegel 100 |2 |6 |4 |2 |10 |24 |48 |
| Riegel 150 | | | | | | | |
| Riegel 200 | | |9 |7 | |16 |32 |
| Riegel 300 | |4 |4 |20 |11 |39 |78 |
| Doppelrohrriegel 150| | | | | | | |
| Doppelrohrriegel 200| | |2 |4 | |6 | |
| | | | | | | |158 |

| Bezeichnung | BS 1 | BS 2 | BS 3 | BS4 | BS 5 | ∑ BS 1-5 | Gelenke |
|---|---|---|---|-----|---|---|---|
| Vertikaldiagonale 100 x H | |4 |4 | |4 |12 |24 |
| Vertikaldiagonale 200 x H | | |18 | | |18 |36 |
| Vertikaldiagonale 300 x H | |2 |2 |8 |4 |16 |32

| Bezeichnung | BS 1 | BS 2 | BS 3 | BS4 | BS 5 | ∑ BS 1-5 | Knotenpunkte |
|---|---|---|---|-----|---|---|---|
| Gewindefußplatte 40 cm 9 1 10 | | | | | | |
| Gewindefußplatte 60 cm 2 4 6 | | | | | | |
| Gewindefußplatte mit Schäkel 3 3 | | | | | | |
| Anfangsstück 6 3 7 16 | | | | | | |

| Bezeichnung | BS 1 | BS 2 | BS 3 | BS4 | BS 5 | ∑ BS 1-5 | Knotenpunkte |
|---|---|---|---|-----|---|---|---|
| Stahlboden 24 mit Rundrohrauflage 100 1 1 | | | | | | |
| Stahlboden 24 mit Rundrohrauflage 300 1 3 4 8 | | | | | | |
| Stahlboden 32 mit Rundrohrauflage 100 2 2 | | | | | | |
| Stahlboden 32 mit Rundrohrauflage 300 2 8 8 18 | | | | | | |
| Durchstiegsboden mit Rundrohraufnahme 300 | | | | | 3 | 3 |

<!--| Bordbrett für Rundrohraufnahme 100 4 4                                    |      |      |      |     |      |          |
>| Bordbrett für Rundrohraufnahme 150 2                                      |      |      |      |     |      |          |
>| Bordbrett für Rundrohraufnahme 200 2 4 6                                  |      |      |      |     |      |          |
>| Bordbrett für Rundrohraufnahme 300 2 4 6                                  |      |      |      |     |      |          |
>| Dreibockkopfteil 1 1                                                      |      |      |      |     |      |          |
>| 28 Abspannkette für Karabiner 1 1                                         |      |      |      |     |      |          |
>| 29 Einsteckring mit Klapp stecker 1 1                                     |      |      |      |     |      |          |
>| 30 Kopfplatte 2 2                                                         |      |      |      |     |      |          |
>| 31 EGSGewinderohr 2 2                                                     |      |      |      |     |      |          |
>| 32 System freies Gewinderohr 350 1 1                                      |      |      |      |     |      |          |
>| 33 Fahrrolle gebremst 4 4                                                 |      |      |      |     |      |          |
>| 34 Fuß plattenkonsole 6 6                                                 |      |      |      |     |      |          |
>| 35 Fuß plattenadapter 3 3                                                 |      |      |      |     |      |          |
>| 36 Gleisrollen totmanngebremst 2                                          |      |      |      |     |      |          |
>| 37 Gleisrollen ungebremst 2                                               |      |      |      |     |      |          |
>| 38 Scheinwerferadapter 4 4                                                |      |      |      |     |      |          |
>| 39 Normalkupplungen 2 4 6                                                 |      |      |      |     |      |          |
>| 40 Drehkupplungen 3 3 6                                                   |      |      |      |     |      |          |
-->

<!--
> [! WARNING]
> [!WARNING]
> **Richtigkeit & Vollständigkeit:** Diese Liste wird manuell gepflegt. Eine Garantie für die Fehlerfreiheit der Mengenangaben kann nicht übernommen werden.
-->

## Einzelteile
### Vertikalstiele
| | Länge Rundstab | Flansche | Vertikalenverbinder |
| - | -: | -: | -: |
| 1,0 m | 129 mm | 2x | 1x |
| 1,5 m | 194 mm | 3x | 1x |
| 2,0 m | 259 mm | 4x | 1x |
| 2,5 m | 324 mm | 5x | 1x |
| 3,0 m | 389 mm | 6x | 1x |

[Anleitung](ZusammenbauVertikale.md)
### Riegel (Horizontalen)
| | Länge Rundstab | Horizontale Keilschlösser | 
| - | -: | -: |
| 1 m | 110 mm | 2x |
| 2 m | 240 mm | 2x |
| 3 m | 370 mm | 2x |

[Anleitung](ZusammenbauRiegel.md)
### Diagonalen
| | Länge Rundstab | Diagonale Keilschlösser | Diagonale Gelenke | Nagel |
| - | -: | -: | -: | -: |
| 1x2 m | 210 mm | 2x | 2x | 2x |
| 2x2 m | 293 mm | 2x | 2x | 2x |
| 2x3 m | 401 mm | 2x | 2x | 2x |

[Anleitung](ZusammenbauDiagonale.md)
### Böden
| | Maße Holzplatte | Bodenadapter breit |  Bodenadapter schmal | 
| - | - | -: | -: |
| 32x300 | 8 x 36 x 369 mm | 2x |
| 32x100 | 8 x 36 x 109 mm | 2x |  |
| 24x300 | 8 x 28 x 369 mm |  | 2x |
| 24x100 | 8 x 28 x 109 mm |  | 2x |

[Anleitung](ZusammenbauBoden.md)
### Sonstige
* [Fuß mit Anfangstück](ZusammenbauFuss.md)
	* Rundstab 44mm
	* 1x Fuß
	* 1x Fußadapter
	* 1x Flansch
* [Anfangstück](ZusammenbauFuss.md)
	* Rundstab 44mm
	* 1x Fußadapter
	* 1x Flansch
* [Drehkupplung](ZusammenbauDrehkupplung.md)
	* 1x Drehkupplung Klemme
	* 1x Drehkupplung Lose
	* 1x Nagel
---
[Zurück zur Hauptanleitung](../README.md)

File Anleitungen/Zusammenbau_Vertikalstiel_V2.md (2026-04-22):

Pro Stiel werden benötigt:

* 1 Oberteil (mit Knotenpunkt)
* 1 Unterteil (ohne Knotenpunkt)
* ? Mittelteile
1 Mittelteil für 1m Stiel
2 Mittelteile für 1,5m Stiel
3 Mittelteile für 2m Stiel
5 Mittelteile für 3m Stiel

Drucken
ausrichten
kleben

Verwendetes Filament: SUNLU PLA+ SILK silver
Sollten Toleranzen nicht ausreichen, kann auch eine Standbohrmaschine helfen ;-)

[Bild]

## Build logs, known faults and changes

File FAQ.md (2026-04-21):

# ❓ Häufig gestellte Fragen (FAQ)

<details>
  <summary><b>Welchen Drucker und welche Einstellungen hast du verwendet?</b></summary><br>
  Das Projekt wurde primär auf einem Creality Ender 3 entwickelt. 
  
  * **Material:** PLA
  * **Schichthöhe:** 0.2mm
  * **Infill:** Mindestens 100%
</details>

<details>
  <summary><b>Warum der ungerade Faktor von 1:7,7?</b></summary><br>
  Im echten EGS sind alle Stangen (Vertikalen/Riegel/Diagonalen) auf einem Ø48mm Rohr aufgebaut. 
  Ich verwende als Basis 6mm Stangen. Es wurde also auf Zielmaterialien desingd und nicht auf gerade Faktoren.
  
  ToDo: Irgendwas stimmt hier noch nicht, die Zahlen passen nicht. In der CAD wurde um von 48,4mm auf 6,2mm zu kommen eine Scalierung von 0.13 verwendet.
</details>

<details>
  <summary><b>Welche Möglichkeiten gibt es die Toleranzen anzupassen?</b></summary><br>
  Der erste und einfachste weg ist es im Sclicer die Scalierung anzupassen. 
  Das Projekt wurde mit PLA entwickelt.

  * PLA  -> 0,2% - 0,5%
  * ABS  -> 0,7% - 1,6%
  * PETG -> 0,2% - 1,0%

  Was bei dem Flansch einen starken unterschied machen kann ist die erste Schicht des Druckes. Versuche den Flansch auf einem Raft zu drucken.
</details>

<details>
  <summary><b>Die Flanschverbindungen wackeln recht viel</b></summary><br>
  Das ist ein noch vorhandenes Problem. Wird das Spiel verkleinert wird es unmöglich die Verbindung zu öffnen oder zu schließen, 
  oder im schlimmsten Fall zerbricht das Keilschloss.
  Wenn du das Spiel weiter einschränken willst schaue bei den Möglichkeiten zu Toleranzanpassung nach.
  
  👉 Solltest du Ideen oder Lösungen zu dem Problem finden kannst du zu diesem Projekt beitragen über ein Issue oder indem du ein Mitglied wirst.
</details>

<details>
  <summary><b>Ich habe ein Problem mit FreeCAD oder möchte das Programm lernen.</b></summary>
  <br>
  Da dieses Projekt rein ehrenamtlich gepflegt wird, können wir leider keinen technischen Support für die Bedienung von FreeCAD anbieten. 
  
  Wenn du FreeCAD lernen möchtest oder Fehlermeldungen hast, die nichts mit unseren Modellen zu tun haben, empfehlen wir die offiziellen Ressourcen der Community:
  
  * 🌐 **[FreeCAD Dokumentation (Wiki)](https://wiki.freecad.org/Main_Page/de)** - Der Einstieg für alle Grundlagen.
  * 🎥 **[Flow de loup (YouTube)](https://www.youtube.com/@Flowdeloup)** - Sehr gute deutsche Tutorials für Einsteiger.
  * 💬 **[FreeCAD Forum](https://forum.freecad.org/)** - Die hilfsbereite Community für spezifische Probleme.
  
  Sollte jedoch ein Fehler **direkt in unseren Dateien** vorliegen (z. B. eine kaputte Verknüpfung), melde dies bitte über einen Issue im Repository.
</details>

---
[Zurück zur Hauptanleitung](README.md)

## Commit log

2026-04-20 Importet Project
    [Boden 3m breit.SLDPRT, Boden 3m breit.STL, Boden 3m schmal.SLDPRT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]
2026-04-20 added materialplanung
2026-04-21 fixed kleinere Fehler in der Formatierung
2026-04-21 Materialliste aus Handbuch
2026-04-21 fixed materialplanung Bausatzliste
2026-04-21 fixed tabelle in materialplanung/Bausätze
2026-04-21 added inhaltsverzeichnis materialplanung
2026-05-11 added Gesammtbau a file for length calculations
    [Gesammtbau.SLDASM]
2026-05-11 changed folder structure to support multiple solutions
    [Boden 3m breit.SLDPRT, Boden 3m breit.STL, Boden 3m schmal.SLDPRT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]
2026-05-11 Added first FreeCAD files
    [Flansch.FCStd, Fuß.FCStd, Fußadapter.FCStd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]
2026-05-11 added second set of FreeCAD files
    [Bodenadapter breit.FCStd, Bodenadapter schmal.FCStd, Diagonale Gelenk.FCStd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]
2026-05-12 Add files via upload
    Schablone zum Positionsgenauen Ausrichten der Flansche an den Holz-Vertikalstielen. Beide Teile sind so klein, dass sie zumindest diagonal auf die meisten Druckplatten passen. Sie werden einfach in d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
    [Schablone EGS Vertikalstiel - Anfangsteil.stl, Schablone EGS Vertikalstiel - Endteil.stl]
2026-05-12 Delete Drucker Dateien/Schablone EGS Vertikalstiel - Anfangsteil.stl
    gelöscht, weil im falschen Verzeichnis
    [Schablone EGS Vertikalstiel - Anfangsteil.stl]
2026-05-12 Delete Drucker Dateien/Schablone EGS Vertikalstiel - Endteil.stl
    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
    [Schablone EGS Vertikalstiel - Endteil.stl]
2026-05-12 Update ZusammenbauVertikale.md
    Erklärung zum Bau der Vertikalstiele mittels Schablone incl. Fotos hinzugefügt
2026-06-24 Boden 1m
    [Boden - 1m - Breit.stl, Boden - 1m - Schmal.stl]
2026-10-04 Korrigierte Längen für die Diagonalen
